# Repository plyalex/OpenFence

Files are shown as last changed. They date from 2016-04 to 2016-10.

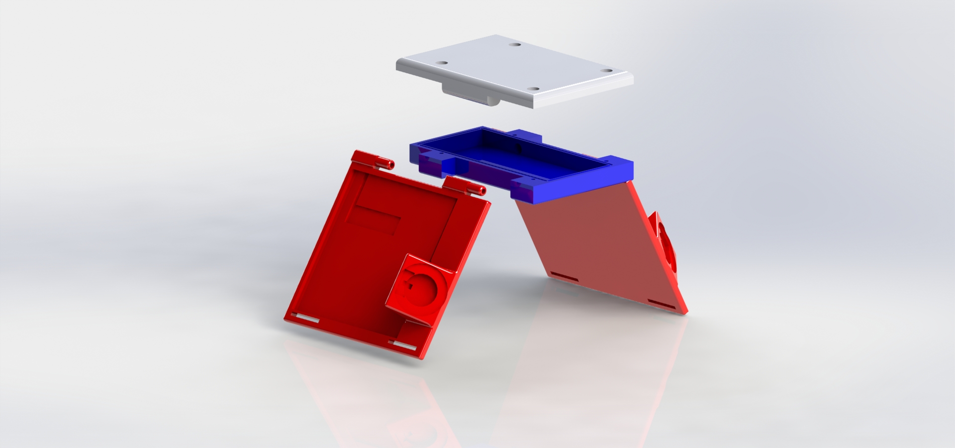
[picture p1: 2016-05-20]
hardware/solidworks/renders/Explodedv2.JPG

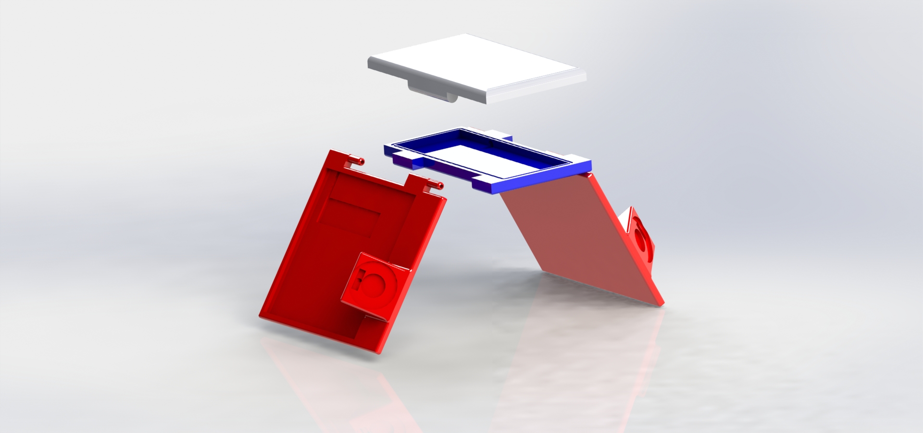
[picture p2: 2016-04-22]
hardware/solidworks/renders/Exploded.JPG

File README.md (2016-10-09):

#OpenFence
OpenFence is a digital livestock fencing system, which uses GPS and stereo audio alerts to contain animals within a specified boundary. 
The location of the fences can be updated using the web interface, and transferred to collar devices wirelessly using LoRa via the in field base station. 
The movements of the animals are logged and transferred to the web, to allow analysis of movements and land utilisation.
#The Purpose
OpenFence is designed to make it easier to implement productive and environmentally friendly grazing practises, such as cell grazing. 
This style of grazing has been shown to increase biodiversity, ground cover, soil carbon and water retention, however it is not commonly implemented due to the additional expenses of fencing and labour.
#Build Details
Go to the [HackaDay.io Page](https://hackaday.io/project/10725-openfence-digital-livestock-fencing)

#[Collar Code](https://github.com/plyalex/OpenFence/tree/master/software/collar/CollarSoftware)
Download and open with Arduino. Additional libraries required are: [TinyGPS++](https://github.com/mikalhart/TinyGPSPlus/releases) and RTCZero.

#Licence
All files: GNU GPL v3

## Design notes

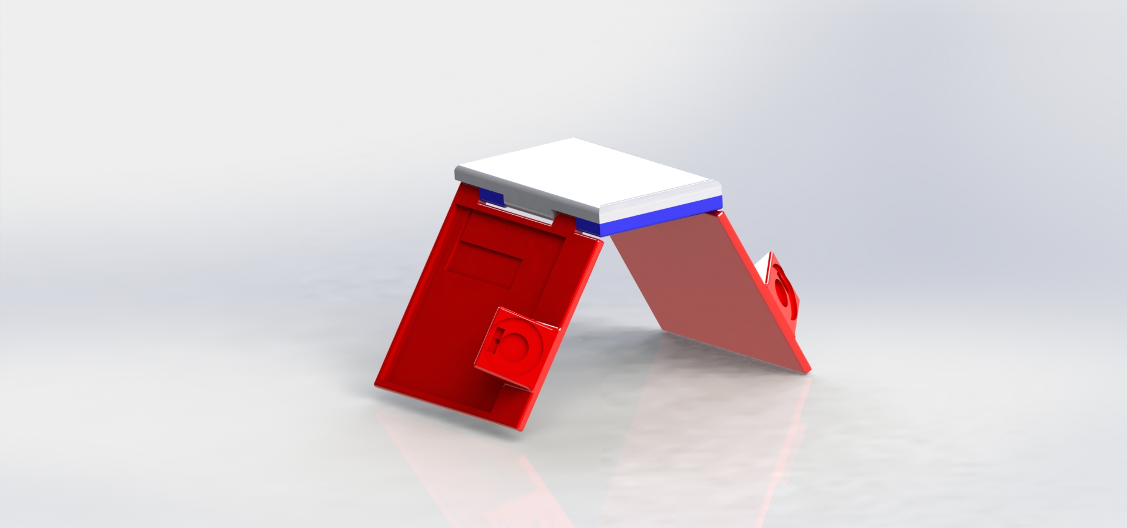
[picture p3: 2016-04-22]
hardware/solidworks/renders/Collar.JPG

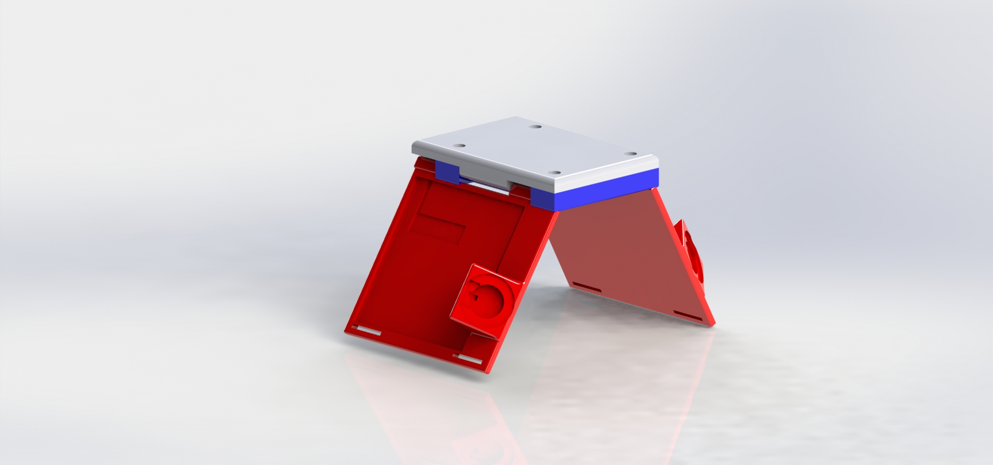
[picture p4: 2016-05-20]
hardware/solidworks/renders/Collarv2.JPG

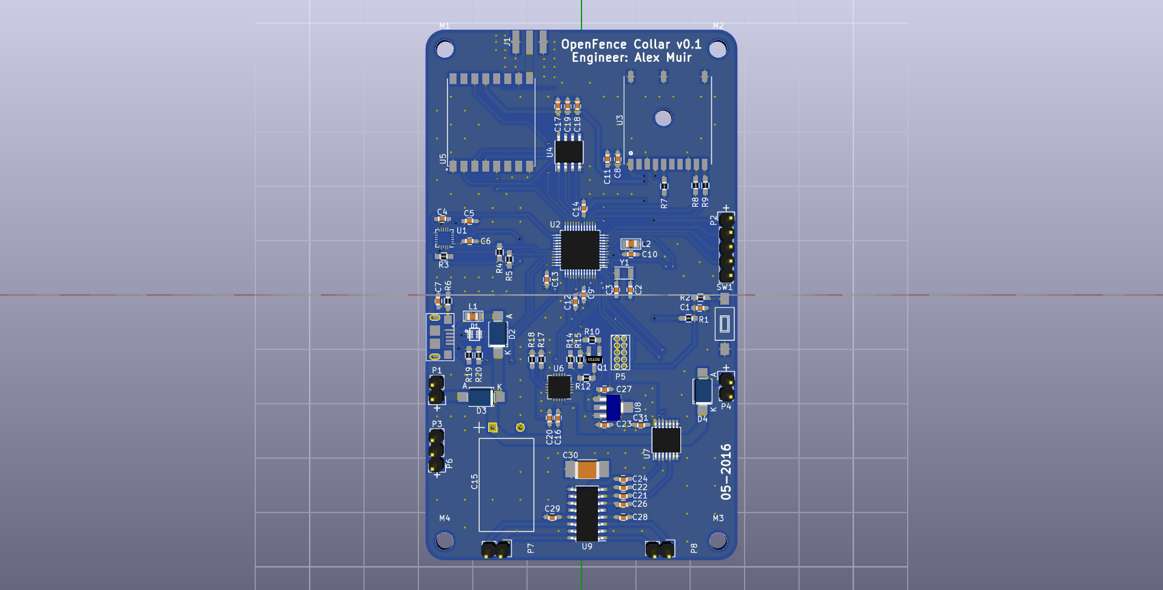
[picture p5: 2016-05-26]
hardware/pcbs/MainCollar/MainCollarRender2.png

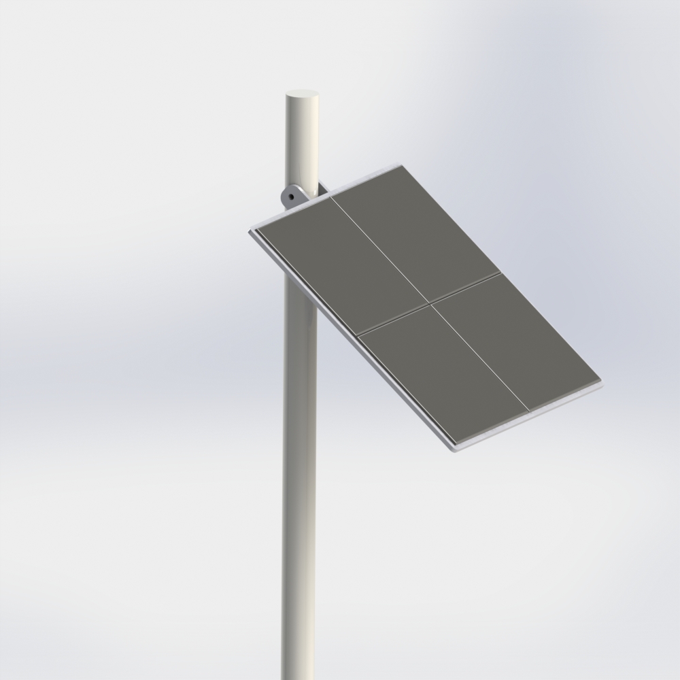
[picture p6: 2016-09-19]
hardware/solidworks/basestation/basestation.JPG

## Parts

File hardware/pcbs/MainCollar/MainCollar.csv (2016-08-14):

 | Reference | Value | Footprint | Datasheet
x | C1 | 0.1uF | Capacitors_SMD:C_0603_HandSoldering
x | C10 | 0.1uF | Capacitors_SMD:C_0603_HandSoldering
x | C11 | 0.01uF | Capacitors_SMD:C_0603_HandSoldering
x | C12 | 1uF | Capacitors_SMD:C_0603_HandSoldering
x | C13 | 0.1uF | Capacitors_SMD:C_0603_HandSoldering
x | C14 | 0.1uF | Capacitors_SMD:C_0603_HandSoldering
x | C15 | 2200uF | OpenFence:Cap1017
x | C16 | 4.7uF | Capacitors_SMD:C_0603_HandSoldering
x | C17 | 0.1uF | Capacitors_SMD:C_0603_HandSoldering
x | C18 | 0.1uF | Capacitors_SMD:C_0603_HandSoldering
x | C19 | 4.7uF | Capacitors_SMD:C_0603_HandSoldering
 | C2 | 18pF | Capacitors_SMD:C_0603_HandSoldering
x | C20 | 4.7uF | Capacitors_SMD:C_0603_HandSoldering
x | C21 | 0.47uF | Capacitors_SMD:C_0603_HandSoldering
x | C22 | 1uF | Capacitors_SMD:C_0603_HandSoldering
x | C23 | 4.7uF | Capacitors_SMD:C_0603_HandSoldering
x | C24 | 0.47uF | Capacitors_SMD:C_0603_HandSoldering
x | C26 | 1uF | Capacitors_SMD:C_0603_HandSoldering
x | C27 | 1uF | Capacitors_SMD:C_0603_HandSoldering
x | C28 | 1uF | Capacitors_SMD:C_0603_HandSoldering
x | C29 | 1uF | Capacitors_SMD:C_0603_HandSoldering
 | C3 | 18pF | Capacitors_SMD:C_0603_HandSoldering
x | C30 | 47uF | Capacitors_SMD:C_1812_HandSoldering
x | C31 | 0.1uF | Capacitors_SMD:C_0603_HandSoldering
x | C4 | 0.1uF | Capacitors_SMD:C_0603_HandSoldering
x | C5 | 0.01uF | Capacitors_SMD:C_0603_HandSoldering
x | C6 | 0.1uF | Capacitors_SMD:C_0603_HandSoldering
x | C7 | 4.7uF | Capacitors_SMD:C_0603_HandSoldering
x | C8 | 1uF | Capacitors_SMD:C_0603_HandSoldering
x | C9 | 0.1uF | Capacitors_SMD:C_0603_HandSoldering
 | D1 | USBLC6-2 | OpenFence:SOT666
x | D2 | SS24 | Diodes_SMD:SMA_Handsoldering
x | D3 | SS24 | Diodes_SMD:SMA_Handsoldering
x | D4 | SS24 | Diodes_SMD:SMA_Handsoldering
 | J1 | SMA-EDGE | RocketScreamKicadLibrary:RF-SMA-EDGE
x | L1 | 600R @ 100MHz | RocketScreamKicadLibrary:IND-0805
x | L2 | 600R @ 100MHz | RocketScreamKicadLibrary:IND-0805
 | P1 | USB_OTG | OpenFence:USB-10118193-0001LF
 | P6 | Battery | Pin_Headers:Pin_Header_Straight_1x03
x | Q1 | 2N7002 | TO_SOT_Packages_SMD:SOT-23_Handsoldering
 | R1 | 10K | Resistors_SMD:R_0603_HandSoldering
 | R10 | 100K | Resistors_SMD:R_0603_HandSoldering
 | R12 | 10K | Resistors_SMD:R_0603_HandSoldering
 | R14 | 270K | Resistors_SMD:R_0603_HandSoldering
 | R15 | 100K | Resistors_SMD:R_0603_HandSoldering
 | R17 | 1K | Resistors_SMD:R_0603_HandSoldering
 | R18 | 50K | Resistors_SMD:R_0603_HandSoldering
 | R19 | 100K | Resistors_SMD:R_0603_HandSoldering
 | R2 | 330 | Resistors_SMD:R_0603_HandSoldering
 | R20 | 330 | Resistors_SMD:R_0603_HandSoldering
 | R3 | 10K | Resistors_SMD:R_0603_HandSoldering
 | R4 | 10K | Resistors_SMD:R_0603_HandSoldering
 | R5 | 10K | Resistors_SMD:R_0603_HandSoldering
 | R6 | 1M | Resistors_SMD:R_0603_HandSoldering
 | R7 | 1K | Resistors_SMD:R_0603_HandSoldering
 | R8 | 1K | Resistors_SMD:R_0603_HandSoldering
 | R9 | 1K | Resistors_SMD:R_0603_HandSoldering
x | SW1 | SW_PUSH | Buttons_Switches_SMD:SW_SPST_FSMSM
 | U1 | MPU9250 | OpenFence:MPU9250
 | U2 | SAMD21G | Housings_QFP:TQFP-48_7x7mm_Pitch0.5mm
x | U3 | PA6C | OpenFence:PA6C
x | U4 | S25FL116K | Housings_SOIC:SOIC-8_3.9x4.9mm_Pitch1.27mm
 | U5 | RF95W | RocketScreamKicadLibrary:RFM9xW
 | U6 | MCP73871 | Housings_DFN_QFN:QFN-20-1EP_4x4mm_Pitch0.5mm
 | U7 | MAX5387 | Housings_SSOP:TSSOP-14_4.4x5mm_Pitch0.65mm
 | U8 | MCP1700T-3302E/MB | TO_SOT_Packages_SMD:SOT89-3_Housing_Handsoldering
 | U9 | PAM8403 | Housings_SOIC:SOIC-16_3.9x9.9mm_Pitch1.27mm
 | Y1 | 32.768kHz | OpenFence:FC-135

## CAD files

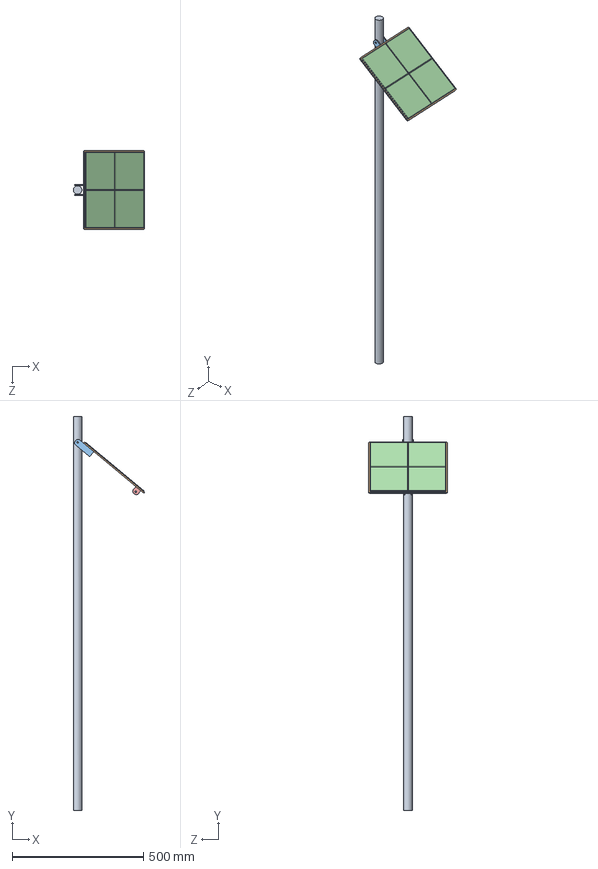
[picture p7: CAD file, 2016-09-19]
hardware/solidworks/basestation/Assem.SLDASM
271.6 x 1500.0 x 300.0 mm
pole
top
toplink x 2
solarpanel x 4
bottomlink x 2

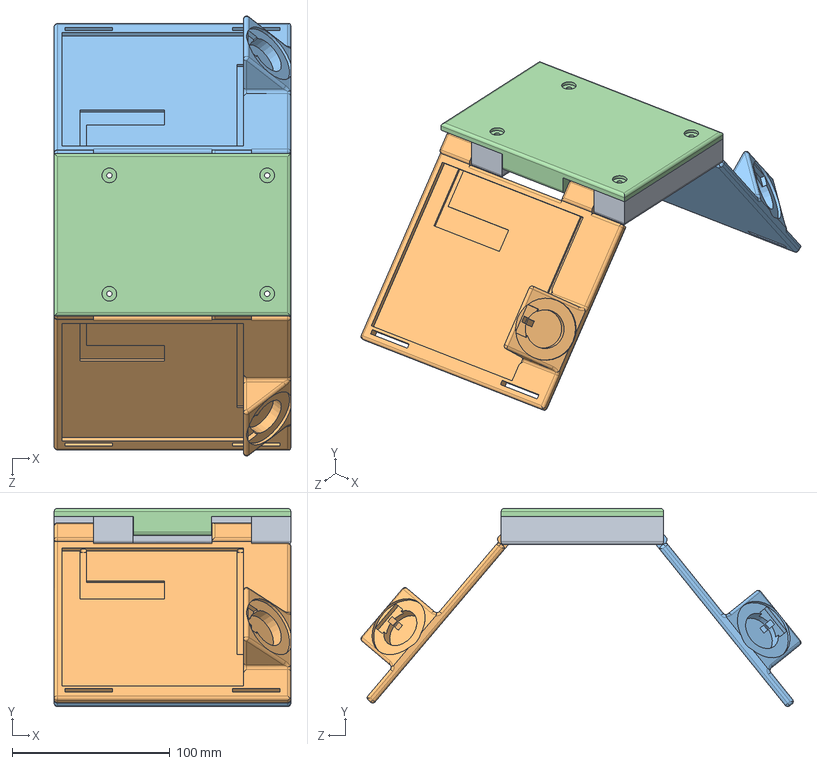
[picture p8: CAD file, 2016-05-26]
hardware/solidworks/Assembly.SLDASM
150.0 x 125.5 x 278.8 mm
BaseTop
RHS
LHS
LidTop
PCB

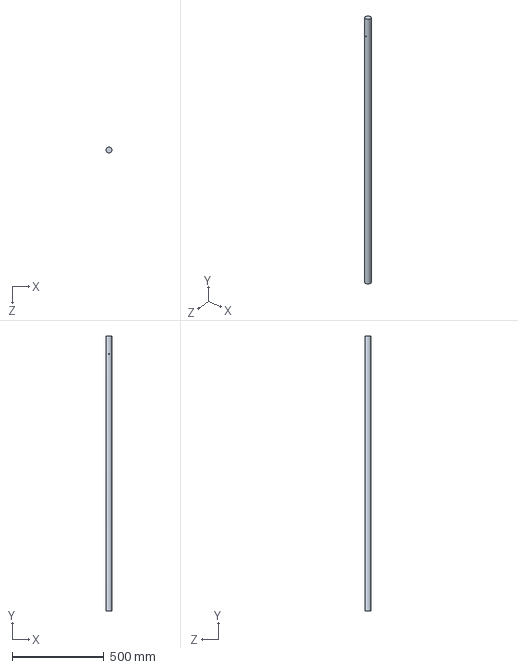
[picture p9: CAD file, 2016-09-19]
hardware/solidworks/basestation/pole.SLDPRT
32.5 x 1500.0 x 32.5 mm

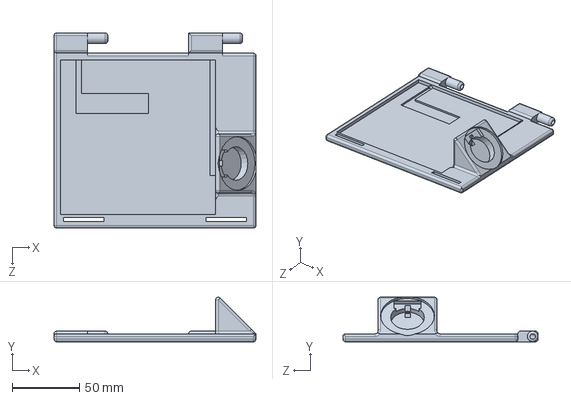
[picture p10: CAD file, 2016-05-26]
hardware/solidworks/RHS.SLDPRT
150.0 x 33.2 x 145.0 mm

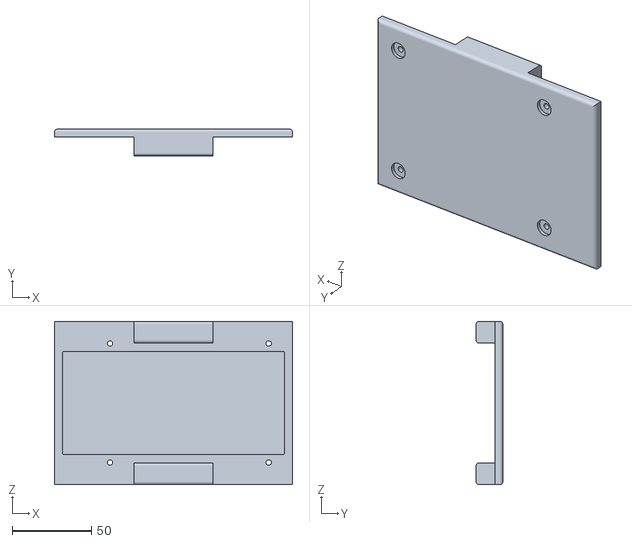
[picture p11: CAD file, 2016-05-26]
hardware/solidworks/stl/Rev2/EnclosureLidRev2.STL
150.0 x 17.0 x 103.0

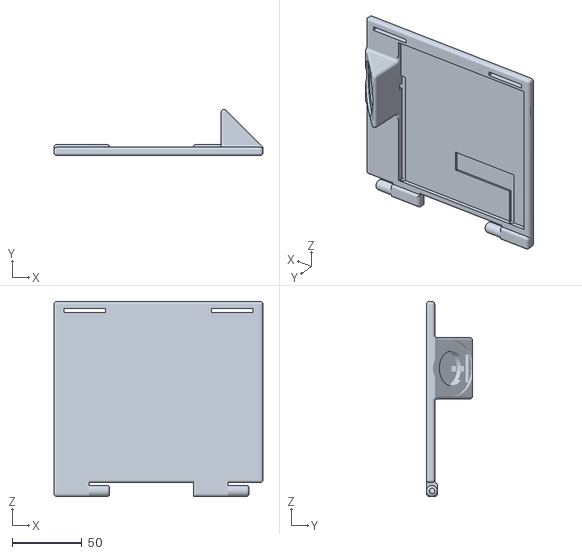
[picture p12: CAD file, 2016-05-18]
hardware/solidworks/stl/RHSRev1.STL
150.0 x 33.2 x 140.0

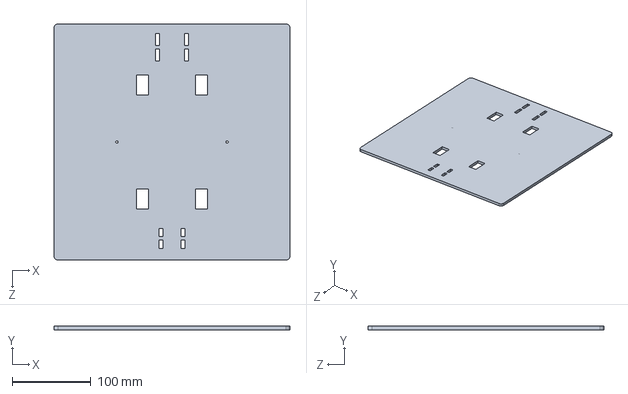
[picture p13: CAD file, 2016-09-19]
hardware/solidworks/basestation/top.SLDPRT
300.0 x 4.50 x 300.0 mm

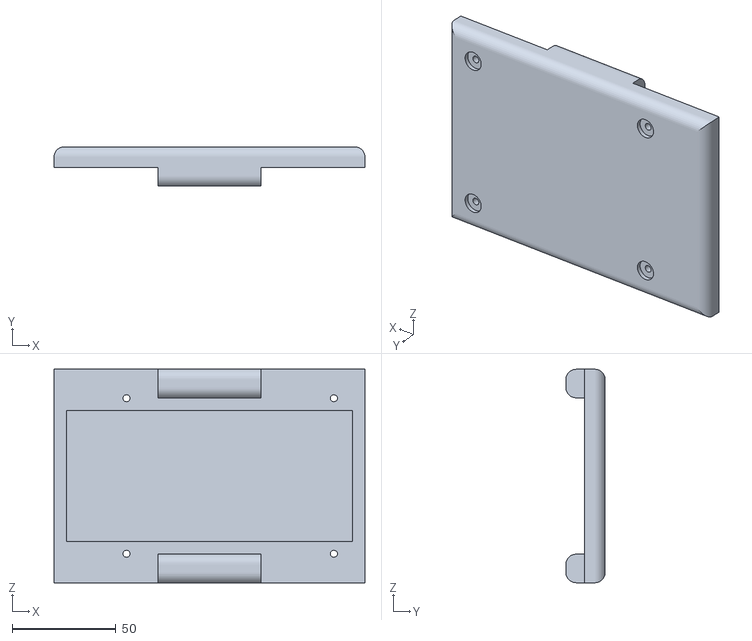
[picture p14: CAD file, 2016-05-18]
hardware/solidworks/stl/LidTopRev1.STL
150.0 x 19.0 x 103.0

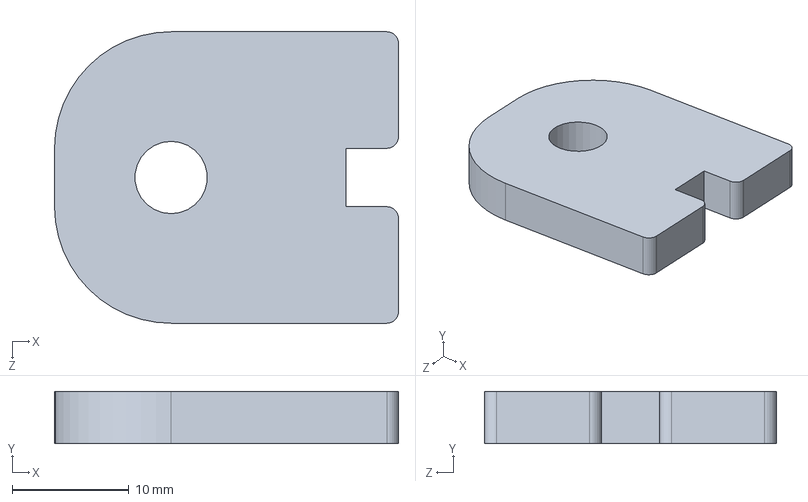
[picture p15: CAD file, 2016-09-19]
hardware/solidworks/basestation/bottomlink.SLDPRT
29.5 x 4.50 x 25.0 mm

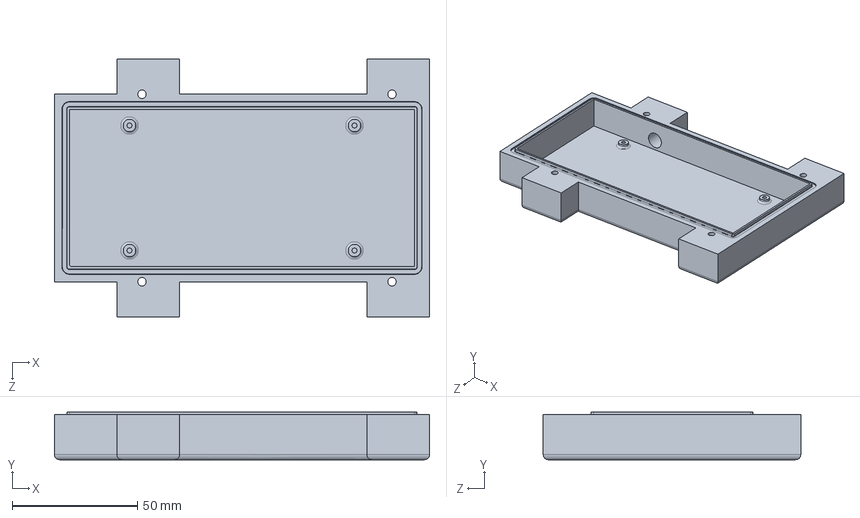
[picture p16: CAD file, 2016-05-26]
hardware/solidworks/BaseTop.SLDPRT
150.0 x 19.0 x 103.0 mm

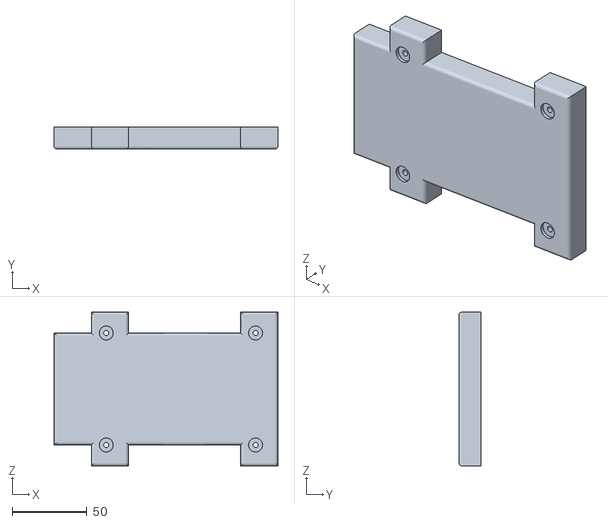
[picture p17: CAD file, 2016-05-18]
hardware/solidworks/stl/BaseTopRev1.STL
150.0 x 15.0 x 103.0

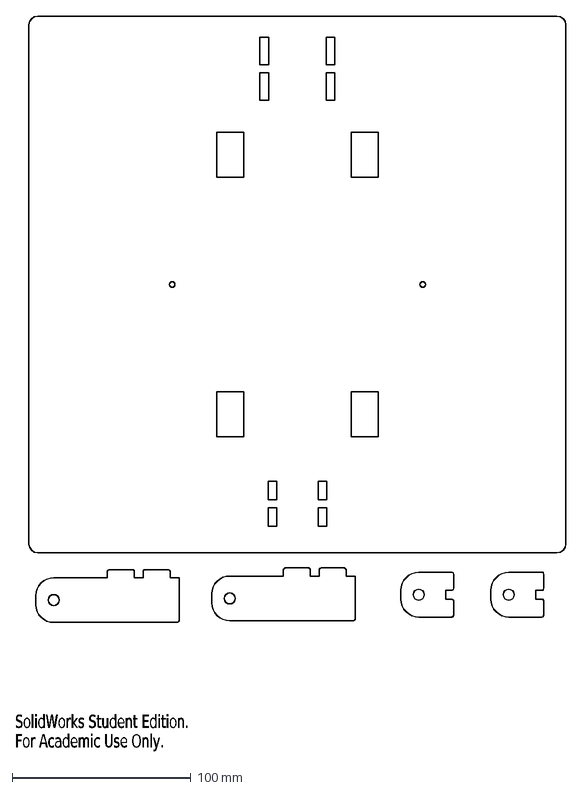
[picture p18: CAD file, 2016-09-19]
hardware/solidworks/basestation/AlexMuir-FYP.DXF
SolidWorks Student Edition.
For Academic Use Only.

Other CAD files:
hardware/solidworks/PCB.sldprt
hardware/solidworks/stl/Rev2/RightSideRev2.STL
hardware/solidworks/stl/LHSrev1.STL
hardware/solidworks/stl/Rev2/LeftSideRev2.STL
hardware/solidworks/LidTop.SLDPRT
hardware/solidworks/stl/Rev2/EnclosureBaseRev2.STL
hardware/solidworks/LHS.SLDPRT
hardware/solidworks/basestation/bottomlink.DXF
hardware/solidworks/basestation/sheet1.SLDDRW
hardware/solidworks/basestation/solarpanel.SLDPRT
hardware/solidworks/basestation/top.DXF
hardware/solidworks/basestation/toplink.DXF
hardware/solidworks/basestation/toplink.SLDPRT

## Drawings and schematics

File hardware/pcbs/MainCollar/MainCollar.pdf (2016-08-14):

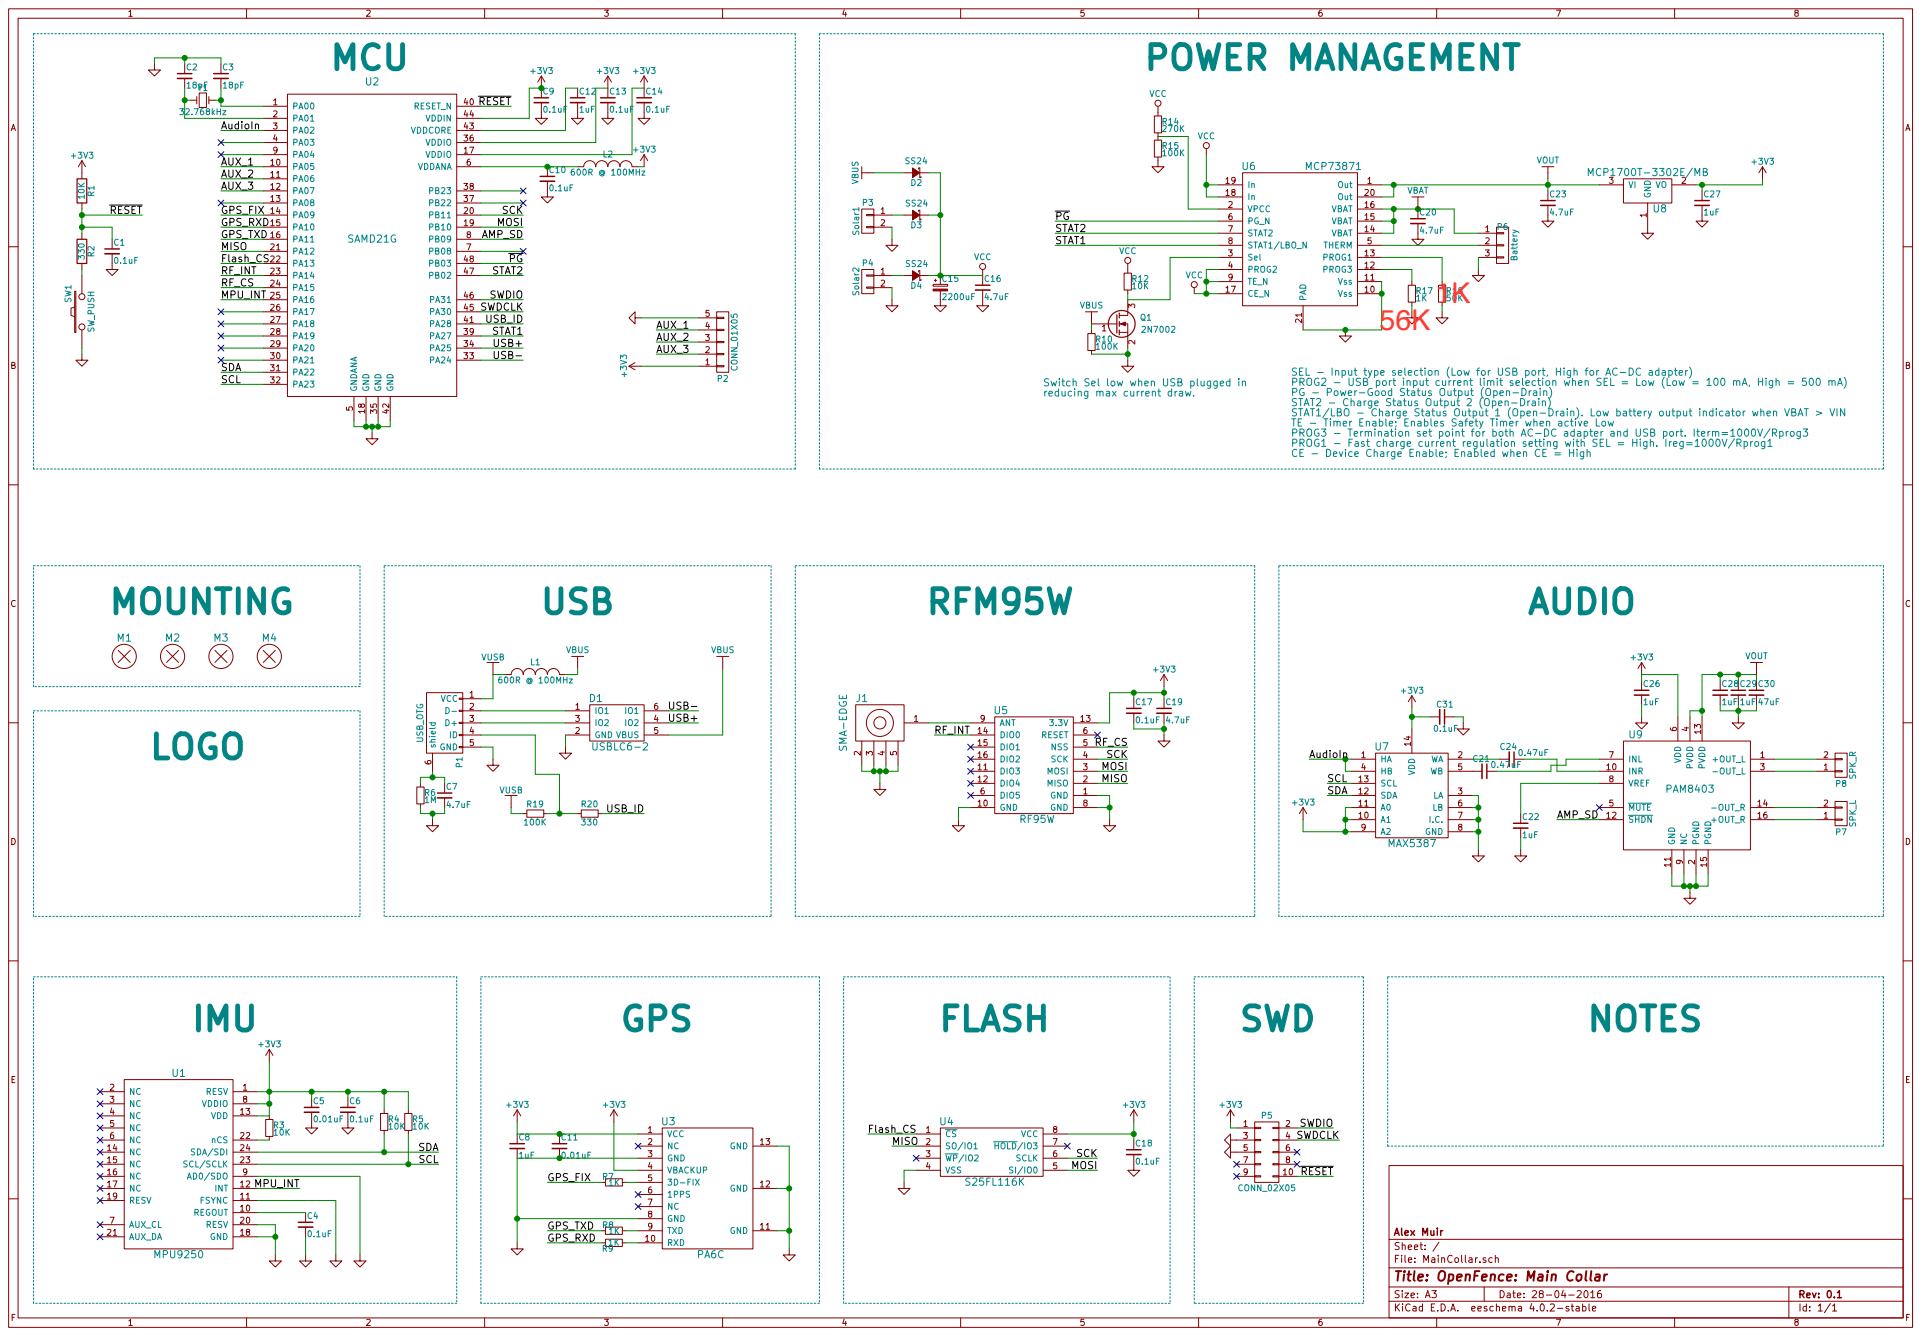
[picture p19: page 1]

PA17 26 | SWDCLK
PA18 27 | USB_ID
PA19 28 | STAT1

SEL - Input type selection (Low for USB port, High for AC-DC adapter)
PROG2 - USB port input current limit selection when SEL = Low (Low = 100 mA, High = 500 mA)
PG - Power-Good Status Output (Open-Drain)
STAT2 - Charge Status Output 2 (Open-Drain)
STAT1/LBO - Charge Status Output 1 (Open-Drain). Low battery output indicator when VBAT > VIN
TE - Timer Enable; Enables Safety Timer when active Low
PROG3 - Termination set point for both AC-DC adapter and USB port. Iterm=1000V/Rprog3
PROG1 - Fast charge current regulation setting with SEL = High. Ireg=1000V/Rprog1
CE - Device Charge Enable; Enabled when CE = High

Switch Sel low when USB plugged in
reducing max current draw.

DIO0 14 DIO1 15 | RF_CS

DIO2 16 | SCK

Alex Muir
Sheet: /
File: MainCollar.sch
Title: OpenFence: Main Collar

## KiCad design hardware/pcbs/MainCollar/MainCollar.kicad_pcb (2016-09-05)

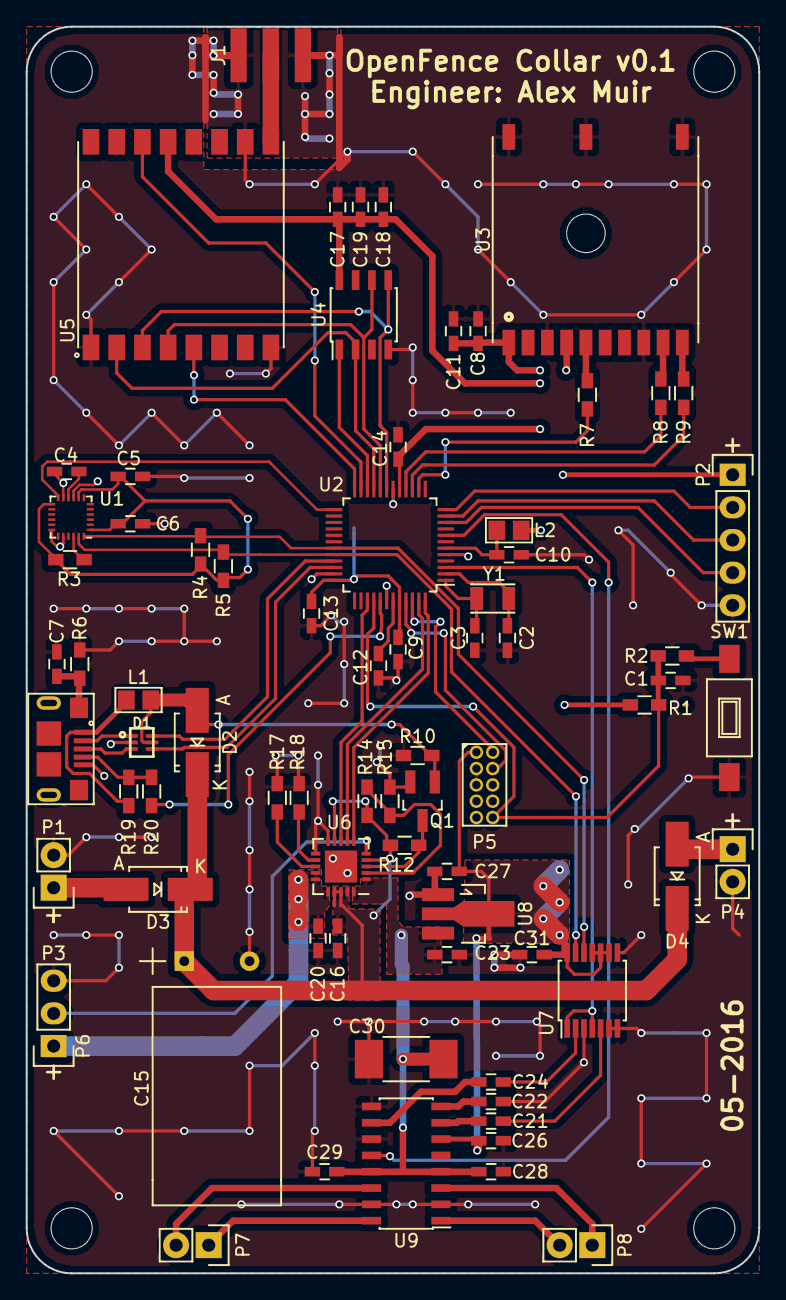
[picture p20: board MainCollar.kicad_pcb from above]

Board: 2 copper layers, 57.0 x 97.0 mm, 78 parts (0 on the bottom side), 64 nets.

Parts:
C1, C4, C6, C9, C10, C13, C14, C17, C18, C31: 0.1uF; C_0603_HandSoldering
C2, C3: 18pF; C_0603_HandSoldering
C5, C11: 0.01uF; C_0603_HandSoldering
C7, C16, C19, C20, C23: 4.7uF; C_0603_HandSoldering
C8, C12, C22, C26, C27, C28, C29: 1uF; C_0603_HandSoldering
C15: 2200uF; Cap1017
C21, C24: 0.47uF; C_0603_HandSoldering
C30: 47uF; C_1812_HandSoldering
D1: USBLC6-2; SOT666
D2, D3, D4: SS24; SMA_Handsoldering
J1: SMA-EDGE; RF-SMA-EDGE
L1, L2: 600R @ 100MHz; IND-0805
M1, M2, M3, M4: Mounting_Hole; MountingHole_3.2mm_M3
P1: USB_OTG; USB-10118193-0001LF
P2: CONN_01X05; Pin_Header_Straight_1x05
P3: Solar1; Pin_Header_Straight_1x02
P4: Solar2; Pin_Header_Straight_1x02
P5: CONN_02X05; HDR_2x5_Pitch1.27mm
P6: Battery; Pin_Header_Straight_1x03
P7: SPK_L; Pin_Header_Straight_1x02
P8: SPK_R; Pin_Header_Straight_1x02
Q1: 2N7002; SOT-23_Handsoldering
R1, R3, R4, R5, R12: 10K; R_0603_HandSoldering
R2, R20: 330; R_0603_HandSoldering
R6: 1M; R_0603_HandSoldering
R7, R8, R9, R17: 1K; R_0603_HandSoldering
R10, R15, R19: 100K; R_0603_HandSoldering
R14: 270K; R_0603_HandSoldering
R18: 50K; R_0603_HandSoldering
SW1: SW_PUSH; SW_SPST_FSMSM
U1: MPU9250
U2: SAMD21G; TQFP-48_7x7mm_Pitch0.5mm
U3: PA6C
U4: S25FL116K; SOIC-8_3.9x4.9mm_Pitch1.27mm
U5: RF95W; RFM9xW
U6: MCP73871; QFN-20-1EP_4x4mm_Pitch0.5mm
U7: MAX5387; TSSOP-14_4.4x5mm_Pitch0.65mm
U8: MCP1700T-3302E/MB; SOT89-3_Housing_Handsoldering
U9: PAM8403; SOIC-16_3.9x9.9mm_Pitch1.27mm
Y1: 32.768kHz; FC-135

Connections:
+3V3: C5.1, C6.1, C8.1, C9.1, C11.1, C13.1, C14.1, C17.1, C18.1, C19.1, C26.1, C27.1, C31.2, L2.2, P2.1, P5.1, R1.1, R3.1, R4.1, R5.1, U1.1, U1.8, U1.13, U2.17, U2.36, U2.44, U3.1, U3.4, U4.8, U5.13, U7.9, U7.10, U7.11, U7.14, U8.2, U9.6
/AMP_SD: U2.8, U9.12
/AUX_1: P2.4, U2.10
/AUX_2: P2.3, U2.11
/AUX_3: P2.2, U2.12
/AudioIn: U2.3, U7.1, U7.4
/Flash_CS: U2.22, U4.1
/GPS_FIX: R7.1, U2.14
/GPS_RXD: R9.2, U2.15
/GPS_TXD: R8.1, U2.16
/MISO: U2.21, U4.2, U5.2
/MOSI: U2.19, U4.5, U5.3
/MPU_INT: U1.12, U2.25
/RF_CS: U2.24, U5.5
/RF_INT: U2.23, U5.14
/SCK: U2.20, U4.6, U5.4
/SCL: R5.2, U1.23, U2.32, U7.13
/SDA: R4.2, U1.24, U2.31, U7.12
/STAT1: U2.39, U6.8
/STAT2: U2.47, U6.7
/SWDCLK: P5.4, U2.45
/SWDIO: P5.2, U2.46
/USB+: D1.4, U2.34
/USB-: D1.6, U2.33
/USB_ID: R20.1, U2.41
/~PG: U2.48, U6.6
/~RESET~: C1.1, P5.10, R1.2, R2.1, U2.40
GND: C1.2, C2.1, C3.1, C4.2, C5.2, C6.2, C7.2, C8.2, C9.2, C10.2, C11.2, C12.2, C13.2, C14.2, C15.2, C16.2, C17.2, C18.2, C19.2, C20.2, C22.2, C23.2, C26.2, C27.2, C28.2, C29.2, C30.2, C31.1, D1.2, J1.2, J1.3, J1.4, J1.5, P1.5, P2.5, P3.2, P4.2, P5.3, P5.5, P6.3, Q1.2, R6.2, R10.2, R15.2, R17.2, R18.2, SW1.1, U1.9, U1.11, U1.18, U1.20, U2.5, U2.18, U2.35, U2.42, U3.3, U3.8, U3.11, U3.12, U3.13, U4.4, U5.1, U5.8, U5.10, U6.10, U6.11, U6.21, U7.3, U7.6, U7.7, U7.8, U8.1, U9.2, U9.9, U9.11, U9.15
unnamed: C2.2, U2.2, Y1.1
unnamed: C3.2, U2.1, Y1.2
unnamed: C4.1, U1.10
unnamed: C7.1, P1.6, R6.1
unnamed: C10.1, L2.1, U2.6
unnamed: C12.1, U2.43
unnamed: C21.1, U9.7
unnamed: C21.2, U7.5
unnamed: C22.1, U9.8
unnamed: C24.1, U9.10
unnamed: C24.2, U7.2
unnamed: D1.1, P1.2
unnamed: D1.3, P1.3
unnamed: D3.2, P3.1
unnamed: D4.2, P4.1
unnamed: J1.1, U5.9
unnamed: P1.4, R19.1, R20.2
unnamed: P6.2, U6.5
unnamed: P7.1, U9.16
unnamed: P7.2, U9.14
unnamed: P8.1, U9.3
unnamed: P8.2, U9.1
unnamed: Q1.3, R12.2, U6.3
unnamed: R2.2, SW1.2
unnamed: R3.2, U1.22
unnamed: R7.2, U3.5
unnamed: R8.2, U3.9
unnamed: R9.1, U3.10
unnamed: R14.2, R15.1, U6.2
unnamed: R17.1, U6.13
unnamed: R18.1, U6.12
VBAT: C20.1, P6.1, U6.14, U6.15, U6.16
VBUS: D1.5, D2.2, L1.2, Q1.1, R10.1
VCC: C15.1, C16.1, D2.1, D3.1, D4.1, R12.1, R14.1, U6.4, U6.9, U6.17, U6.18, U6.19
VOUT: C23.1, C28.1, C29.1, C30.1, U6.1, U6.20, U8.3, U9.4, U9.13
VUSB: L1.1, P1.1, R19.2

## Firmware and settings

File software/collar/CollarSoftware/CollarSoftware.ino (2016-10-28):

#include "PinDefines.h"
#include "MCP73871.h"
#include "MPU9250.h"
#include "Audio_OF.h"
#include "LoRa_OF.h"
#include "Geofence.h"
#include <Wire.h>
#include <SPI.h>
#include <RTCZero.h>
#include <TinyGPS++.h>
#include "Flash_OF.h"


#define GPSTestPoints
uint8_t NODE_ADDRESS = 103;
uint8_t distThresh = 2;
uint8_t motionThresh = 3;
bool testing = true;
int16_t magbias0 = -270;
int16_t magbias1 = 168;
int16_t magbias2 = -70;

uint8_t polyCorners = 0;
struct position fencePoints[256];
uint8_t fenceversion = 0;

MCP73871 battery;
RTCZero rtc;
TinyGPSPlus gps;
MPU9250 mpu9250;
Audio_OF audio;
LoRa_OF lora;
Flash_OF flash;
Geofence fence;


// magbias[]={-90,400,0}; //Float in MPU9250.h library


position me, metransmitted;
datetime nowdt;
int alerts = 0;
int shocks = 0;
int sleepCounter = 0;




void setup() {
  init_pins();
  init_comms();
  delay(3000);
  init_gps();
  audio.initAudio();
  rtc.begin(); // initialize RTC

  fencePoints[0].lon=145.138458;  
  fencePoints[0].lat=-37.911625; 
  fencePoints[1].lon=145.138707;
  fencePoints[1].lat=-37.911662;
  fencePoints[2].lon=145.138653;
  fencePoints[2].lat=-37.911887;
  fencePoints[3].lon=145.138399; 
  fencePoints[3].lat=-37.911850;
  polyCorners=4;

  delay(1000);
  lora.initLoRa();
  flash.init();  
  lora.setAddress();

  SerialUSB.print(magbias0); SerialUSB.print("\t");
  SerialUSB.print(magbias1); SerialUSB.print("\t");
  SerialUSB.print(magbias2); SerialUSB.println("\t");

  init_mpu();


// Re enable me for sleep mode??
 // mpu9250.wakeOnmotion(motionThresh);
 // mpu9250.readStatus();


  // while(1){
  //   float compass = mpu9250.getHeading();
  //   compass = compass + 11.716667;
  //   SerialUSB.println(compass);
  //   // while (GPSSerial.available())
  //   //   SerialUSB.write(GPSSerial.read());
  //   delay(200);
  // }

  // int vol = 50;
  // while(1){
  //   SerialUSB.print("Volume: "); SerialUSB.println(vol);
  //   audio.enableAmp(); 
  //   audio.setvolumeBoth(vol); 
  //   delay(1500);
  //   vol=vol+2; 
  //   audio.disableAmp(); 
  //   delay(1000);
  // }

  testing = 1;
  // motionThresh = 3;

  

  SerialUSB.print(NODE_ADDRESS); SerialUSB.print("\t");
  SerialUSB.print(polyCorners); SerialUSB.print("\t");
  SerialUSB.print(fenceversion); SerialUSB.print("\t");
  SerialUSB.print(fencePoints[0].lat,7); SerialUSB.print("\t");
  SerialUSB.print(fencePoints[1].lat,7); SerialUSB.print("\t");
  SerialUSB.print(fencePoints[2].lat,7); SerialUSB.print("\t");
  SerialUSB.println(fencePoints[3].lat,7);
  SerialUSB.print(magbias0); SerialUSB.print("\t");
  SerialUSB.print(magbias1); SerialUSB.print("\t");
  SerialUSB.print(magbias2); SerialUSB.println("\t");

  SerialUSB.println("Setup Complete");
  audio.enableAmp(); audio.setvolumeBoth(20); delay(500); audio.disableAmp(); // Short Beep

  if(testing){
    audio.enableAmp(); audio.setvolumeBoth(20); delay(500); audio.disableAmp(); //Beep Beep
    delay(500); audio.enableAmp(); delay(500); audio.disableAmp();
    me.lat=-37.909507; 
    me.lon=145.135128;
    nowdt.time=60005;
    nowdt.date=191016;
    metransmitted=me;
  }

  if(!testing){
    SerialUSB.print("Getting GPS Fix");
    while(!gps.location.isValid())
      smartDelay(500);
    SerialUSB.println("Fix Obtained");
    updateMeNowDT();
    metransmitted=me;

    audio.enableAmp(); audio.setvolumeBoth(20); delay(500); audio.disableAmp(); //Beep Beep
    delay(500); audio.enableAmp(); delay(500); audio.disableAmp();
  }
}

void loop() {
  

  //battery.printStatus();
  //SerialUSB.println(battery.getStatus(),BIN);
  //SerialUSB.println(fencePoints[0].lat);

  if(!testing){
    updateMeNowDT();
  // } else {
  //   byte seconds=rtc.getSeconds();
  //   if(seconds < 10){     //Inside
  //     me.lat=-37.911765; 
  //     me.lon=145.138300;
  //     nowdt.time=51810;
  //     nowdt.date=240516;
  //   }else if(seconds <20){
  //     me.lat=-37.911643; 
  //     me.lon= 145.137766;
  //     nowdt.time=51820;
  //     nowdt.date=240516;
  //   }else if(seconds <30){
  //     me.lat=-37.911623;
  //     me.lon=145.137901;
  //     nowdt.time=51830;
  //     nowdt.date=240516;
  //   }else if(seconds <40){
  //     me.lat=-37.911520;
  //     me.lon=145.138454;
  //     nowdt.time=51840;
  //     nowdt.date=240516;
  //   }else if(seconds <50){
  //     me.lat=-37.911997;
  //     me.lon=145.138565;
  //     nowdt.time=51850;
  //     nowdt.date=240516;
  //   }else if(seconds <60){
  //     me.lat=-37.912090;
  //     me.lon=145.138230;
  //     nowdt.time=51900;
  //     nowdt.date=240516;
  //   }
  // }
  } else {
    byte seconds=rtc.getSeconds();
    if(seconds < 5){     //Inside
      me.lat=-37.909507; 
      me.lon=145.135128;
      nowdt.time=60005;
      nowdt.date=191016;
    }else if(seconds <10){ //inside
      me.lat=-37.909630; 
      me.lon= 145.135133;
      nowdt.time=60010;
      nowdt.date=191016;
    }else if(seconds <15){ //outside
      me.lat=-37.909624; 
      me.lon=145.135013;
      nowdt.time=60015;
      nowdt.date=191016;
    }else if(seconds <20){ //outside
      me.lat=-37.909623; 
      me.lon=145.134983;
      nowdt.time=60020;
      nowdt.date=191016;
    }else if(seconds <25){ //outside
      me.lat=-37.909623; 
      me.lon=145.134972;
      nowdt.time=60025;
      nowdt.date=191016;
    }else if(seconds <30){ //outside
      me.lat=-37.909673; 
      me.lon=145.134976;
      nowdt.time=60030;
      nowdt.date=191016;
    }else if(seconds <35){ //outside
      me.lat=-37.909704; 
      me.lon=145.135008;
      nowdt.time=60035;
      nowdt.date=191016;
    }else if(seconds <40){ //inside
      me.lat=-37.909729; 
      me.lon= 145.135105;
      nowdt.time=60040;
      nowdt.date=191016;
    }else if(seconds <45){ //inside
      me.lat=-37.909750;
      me.lon=145.135287;
      nowdt.time=60005;
      nowdt.date=191016;
    }else if(seconds <50){ //inside
      me.lat=-37.909647; 
      me.lon=145.135288;
      nowdt.time=60050;
      nowdt.date=191016;
    }else if(seconds <55){ //inside
      me.lat=-37.909506; 
      me.lon=145.135305;
      nowdt.time=60055;
      nowdt.date=191016;
    }
  }

  if(fence.distance(me, metransmitted) > distThresh){
    sleepCounter = 0; //Recent Movement
    //SerialUSB.println("Sending Packet");
    if(lora.sendPosition(me, nowdt, alerts, shocks, fenceversion)){
      // audio.enableAmp(); audio.setvolumeBoth(20); delay(500); audio.disableAmp(); //Beep Beep Failed to Send
      // delay(500); audio.enableAmp(); delay(500); audio.disableAmp();
    } else {
      metransmitted=me;
    }
  }



  fenceProperty result=fence.geofence(me, fencePoints, polyCorners);

  float compass = mpu9250.getHeading();

  
  SerialUSB.println(compass);


  static bool outside;

  if(result.distance > 0){
    SerialUSB.print("Side: \t");
    SerialUSB.print(result.sideOutside);
    SerialUSB.print("\t Distance: \t");
    SerialUSB.print(result.distance);
    SerialUSB.print("\t Azimuth: \t");
    SerialUSB.print(result.bearing);
    SerialUSB.print("\t Compass: \t");
    SerialUSB.print(compass);
    SerialUSB.println("\t C+var-A: \t");


    if(!outside){
      alerts++;
      outside=1;
    } 
    
    int volume = result.distance * 10; //10;
    //if(volume>10) volume=10;
    if(volume>50) volume=50;
    audio.enableAmp();
    audio.setvolumeBoth(volume);
    // delay(1000);
    // audio.disableAmp();

    int val = compass + 11.716667 + result.bearing;
    while(abs(val)>180){
      if(val > 180) val=val-360;
      else if(val < -180) val=val+360;
    }
    SerialUSB.println(val);

    if(val>0){
      if(val>90){
        audio.setvolumeBoth(0);
        audio.disableAmp();
      }
      else{
        //Sound RHS
        audio.enableAmp();
        audio.setvolumeLeft(0);
        audio.setvolumeRight(volume);
      } 
    }
    else{
      if(val < -90){
        audio.setvolumeBoth(0);
        audio.disableAmp();
      }
      else{
        //Sound LHS
        audio.enableAmp();
        audio.setvolumeRight(0);
        audio.setvolumeLeft(volume);
      } 
    }
  }else{
    outside=0;
    audio.setvolumeBoth(0);
    audio.disableAmp();
  }

  smartDelay(500);
  
  sleepCounter++;
  if(sleepCounter > 15 & !outside & !testing){
    sleepCounter=0;
    //audio.enableAmp(); audio.setvolumeBoth(20); delay(1000); audio.disableAmp(); // Long Beep    
    standby();
    //audio.enableAmp(); audio.setvolumeBoth(20); delay(500); audio.disableAmp(); // Short Beep
  }

}


static void smartDelay(unsigned long ms)
{
  unsigned long start = millis();
  do 
  {
    while (GPSSerial.available())
      gps.encode(GPSSerial.read());
  } while (millis() - start < ms);
}

void updateMeNowDT(){
  if (gps.location.isValid())
  {
    me.lat=gps.location.lat();
    me.lon=gps.location.lng();
  }
  if (gps.date.isValid())
  {
    nowdt.date=gps.date.value();
  }      
  if (gps.time.isValid())
  {
    nowdt.time=gps.time.value()/100; //Divide by 100 to remove fractions of a second
  } 
}

void standbyGPS(){
  GPSSerial.println("$PMTK161,0*28"); //Send GPS to Standby (wake with any char)
  delay(100);  //Ensure the GPS Serial Message has time to complete before sleeping
}

void standbyMode()
{
  SCB->SCR |= SCB_SCR_SLEEPDEEP_Msk;
  __DSB();
  __WFI();
  return;
}

void wake(){
  mpu9250.readStatus();
  return;
}

void standby(){
  standbyGPS();
  lora.sleep();
  audio.disableAmp();
  mpu9250.wakeOnmotion(motionThresh);
  mpu9250.readStatus();
  attachInterrupt(11, wake, HIGH);
  USBDevice.detach();
  delay(100);
  //USBDevice.detach();
  
  standbyMode();

  detachInterrupt(11);
  USBDevice.attach();
  standbyGPS();  //wakes GPS back up

  return;
}

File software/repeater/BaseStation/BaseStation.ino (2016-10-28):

// ***** INCLUDES *****
#include <RHReliableDatagram.h>
#include <RH_RF95.h>
#include <SPI.h>

// ***** CONSTANTS *****
#define BASE_STATION_ADDRESS 1
#define SerialMethod SerialUSB
//#define SerialMethod Serial1


// ***** PIN DEFINITION *****
// ***** MINI ULTRA PRO CONFIGURATIONS *****
const int radioInterruptPin = 2;  // D2 is used as radio interrupt pin
const int flashChipSelectPin = 4; // D4 is used as serial flash chip select pin
const int radioChipSelectPin = 5; // D5 is used as radio chip select pin
const int ledPin = 13;            // D13 has an LED 

// Singleton instance of the radio driver
RH_RF95 radio(radioChipSelectPin, radioInterruptPin);

// Class to manage message delivery and receipt, using the driver declared above
RHReliableDatagram manager(radio, BASE_STATION_ADDRESS);


uint8_t buf[RH_RF95_MAX_MESSAGE_LEN];
uint8_t buffer[20];

struct datapacket0{ //Animal Locations
  float lat;
  float lon;
  uint32_t gpstime;
  uint32_t date;
  uint16_t alerts; 
  uint8_t shocks;
  uint8_t ver;
};

struct datapacket1{ //Fence Locations
  uint8_t ver;
  uint8_t last;
  uint8_t numPts;
  uint8_t X;
  float lat0;
  float lon0;
  float lat1;
  float lon1;
};

struct datapacket2{ //Settings
  bool updated;
  uint8_t New_RF_ID;
  uint8_t distThresh;
  uint8_t motionThresh;
  bool testing;
  //uint8_t Padding will be added
  int16_t magbias0;
  int16_t magbias1;
  int16_t magbias2;
};

struct position{
  float lat; //x
  float lon; //y
};

int polyCorners = 0;
uint8_t fenceversion;


struct datapacket0 d0; //Received Location 
struct datapacket1 d1[128]; //Fence Locations
struct datapacket2 d2[256]; //Collar Settings


void setup() 
{
  // Ensure serial flash is not interfering with radio communication on SPI bus
  pinMode(flashChipSelectPin, OUTPUT);
  digitalWrite(flashChipSelectPin, HIGH);
  
  pinMode(ledPin, OUTPUT);
  digitalWrite(ledPin, LOW);
    
  SerialMethod.begin(57600);
  digitalWrite(ledPin, HIGH);
  // If radio initialization fail
  if (!manager.init())
  {
    SerialMethod.println("Init failed");
  }
  else SerialMethod.println("Init Success");

  digitalWrite(ledPin, LOW);


  // FSK, Rb = 2.4 kbps, Fd = 4.8 kHz 915 MHz, 20 dBm on RFM69HCW
  radio.setModemConfig(RH_RF95::Bw500Cr45Sf128 );
  radio.setFrequency(915.0);
  radio.setTxPower(5);


  d1[0].ver=1;
  d1[0].last=0;
  d1[0].numPts=3;
  d1[0].X=0;
  d1[0].lon0=101.101101;  
  d1[0].lat0=-37.911625; 
  d1[0].lon1=145.138707;
  d1[0].lat1=-37.911662;
  d1[1].ver=1;
  d1[1].last=1;
  d1[1].numPts=3;
  d1[1].X=2;
  d1[1].lon0=145.138653;
  d1[1].lat0=-37.911887;
  d1[1].lon1=0;
  d1[1].lat1=0;
}



void loop()
{


  uint8_t flag=0;
  uint8_t index=0;
  uint8_t length=0;

  if(SerialMethod.available()){

    flag = SerialMethod.read();
    length = SerialMethod.read();
    if(length > 20) length = 20;

    for(int j=0; j<length; j++){
      buffer[j]=SerialMethod.read();
    }

    switch(flag){
      case 1: //New Fence locations
              memcpy(&index,          &buffer[3],  1);
              index=index>>1; //Divide by two

              if(index==0) memset(&d1[0], 0, sizeof(d1));  //If new set of fence points, remove the old ones.

              memcpy(&d1[index].ver,       &buffer[0],  1);   //Dest, Orig, Bytes
              memcpy(&d1[index].last,      &buffer[1],  1);
              memcpy(&d1[index].numPts,    &buffer[2],  1);
              memcpy(&d1[index].X,         &buffer[3],  1);
              memcpy(&d1[index].lat0,      &buffer[4],  4);
              memcpy(&d1[index].lon0,      &buffer[8],  4);
              memcpy(&d1[index].lat1,      &buffer[12], 4);
              memcpy(&d1[index].lon1,      &buffer[16], 4);
              break;

      case 2: //Setting Update
              memcpy(&index,          &buffer[0],  1); //RF_ID
              d2[index].updated = 1;

              memcpy(&d2[index].New_RF_ID,      &buffer[1],  1);   //Dest, Orig, Bytes
              memcpy(&d2[index].distThresh,     &buffer[2],  1);
              memcpy(&d2[index].motionThresh,   &buffer[3],  1);
              memcpy(&d2[index].testing,        &buffer[4],  1);
              memcpy(&d2[index].magbias0,       &buffer[5],  2);
              memcpy(&d2[index].magbias1,       &buffer[7],  2);
              memcpy(&d2[index].magbias2,       &buffer[9],  2);
              break;

    }
    
}

  // Message available from mobile node?
  if (manager.available())
  {
    uint8_t len = sizeof(buf);
    uint8_t from;
    uint8_t* bufPtr;
    digitalWrite(ledPin, HIGH);  
    // Now wait for a reply from the mobile node
    if (manager.recvfromAck(buf, &len, &from))
    {
      uint8_t flagfromNode = radio.headerFlags();
      switch(flagfromNode){
        case 0: //Location packet
                memcpy(&d0.lat,      &buf[0],  4);   //Dest, Orig, Bytes
                memcpy(&d0.lon,      &buf[4],  4);
                memcpy(&d0.gpstime,  &buf[8],  4);
                memcpy(&d0.date,     &buf[12], 4);
                memcpy(&d0.alerts,   &buf[16], 2);
                memcpy(&d0.shocks,   &buf[18], 1);
                memcpy(&d0.ver,      &buf[19], 1);


                SerialMethod.write((uint8_t *)&flagfromNode,1);
                SerialMethod.write((uint8_t *)&from,1);
                SerialMethod.write((uint8_t *)&d0,20);
                SerialMethod.println();

          //Human Readable
                // SerialMethod.print(from); SerialMethod.print(","); SerialMethod.print(radio.headerFlags());SerialMethod.print(",");
                // SerialMethod.print(d0.lat,6); SerialMethod.print(d0.lon,6); SerialMethod.print(","); SerialMethod.print(d0.gpstime);
                // SerialMethod.print(","); SerialMethod.print(d0.date); SerialMethod.print(","); SerialMethod.print(d0.alerts);
                // SerialMethod.print(","); SerialMethod.print(d0.shocks); SerialMethod.print(","); SerialMethod.print(d0.ver);
                
                // SerialMethod.print(from); SerialMethod.print(","); SerialMethod.print(radio.lastRssi()); SerialMethod.print(",");
                // SerialMethod.print(d0.shocks); SerialMethod.print(","); SerialMethod.print(d0.lat,6); SerialMethod.print(","); 
                // SerialMethod.print(d0.lon,6); SerialMethod.println();

                break;
        case 1: //Fence packet
                break;
        case 2: //Settings Packet
                break;
        case 3: //Bias Packet
                int16_t magbias0,magbias1,magbias2;
                memcpy(&magbias0,  &buf[0],  2);   //Dest, Orig, Bytes
                memcpy(&magbias1,  &buf[2],  2);
                memcpy(&magbias2,  &buf[4],  2);

                SerialMethod.write((uint8_t *)&flagfromNode,1);
                SerialMethod.write((uint8_t *)&from,1);
                SerialMethod.write((uint8_t *)&buf,6);
                SerialMethod.println();
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

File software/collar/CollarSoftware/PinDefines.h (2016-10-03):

#ifndef PinDefines_h
#define PinDefines_h
	#include "Geofence.h"

	//I2C Addresses: MPU 0x68, POT 0x2F
	//GPS_TX, RX = Serial1
	//Serial Monitor = SerialUSB

	#define DAC_OUT     A0
	#define AMP_EN      A2
	#define AUX_0       9
	#define AUX_1       8
	#define AUX_2       A4
	#define GPS_FIX     3
	#define FLASH_CS    ATN
	#define RF_INT      2
	#define RF_CS       5
	#define MPU_INT     11
	#define CHARGE_S1   26 //PIN_LED_TXL
	#define CHARGE_S2   A5
	#define CHARGE_PG   25 //PIN_LED_RXL

	#define GPSSerial 	Serial1
	
	//Global Variables - Updatable in Web Interface
	extern uint8_t NODE_ADDRESS;
	extern uint8_t distThresh;
	extern uint8_t motionThresh;
	extern bool testing;
	extern int16_t magbias0;
	extern int16_t magbias1;
	extern int16_t magbias2;

	extern uint8_t polyCorners;
    extern struct position fencePoints[256];
    extern uint8_t fenceversion;

#endif

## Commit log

2016-05-12 Schematics almost complete
    [MainCollar.kicad_pcb, MainCollar.sch]
2016-05-12 Creating an Arduino library for the PA6C GPS
2016-05-14 Initial PCB component placement
    [MainCollar.kicad_pcb, MainCollar.sch]
2016-05-16 PCB Prototype Completed
    [MainCollar-B.Cu.gbr, MainCollar-B.Mask.gbr, MainCollar-Edge.Cuts.gbr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]
2016-05-18 Initial prototype design ready for 3D printing.
    [Assembly.SLDASM, BaseTop.SLDPRT, BaseTopRev1.STL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]
2016-05-26 Second version ready for 3D printing.
    [Assembly.SLDASM, BaseTop.SLDPRT, EnclosureBaseRev2.STL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]
2016-05-26 Renders for displaying the PCB
    [MainCollar.kicad_pcb]
2016-08-14 Updating for mistakes
    [MainCollar.csv, MainCollar.kicad_pcb]
2016-08-14 Updating for custom PCB
2016-08-15 Added Tilt corrected compass heading.
    Using the function getHeading() will return a float value of the
    compass heading adjusted based on the accelerometer orientation.
    [MPU9250.h]
2016-08-15 Added bearing2fence function
    bearing2fence() returns the Azimuth between the closest point on the
    fence and the collar device.
2016-08-28 Updating Collar firmware
    Added ability to update fence locations over LoRa.
    Using PWM output for the audio alert.
    Updated the Geofence functionality such that it returns the side
    outside, the distance outside and the bearing of the fence to the
    collar.
2016-08-28 Initial Commit of baseStation Arduino code
2016-09-05 Switched R17 and R18 to be in correct locations
    [MainCollar.kicad_pcb, MainCollar.sch]
2016-09-05 Implemented Send to Devices button
2016-09-06 Custom Board Testing - Using OSCULP32K as clock
    [arduino_zero.cfg]
2016-09-19 Basestation solid works design
    [AlexMuir-FYP.DXF, Assem.SLDASM, bottomlink.DXF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]
2016-09-19 Update board settings from LoRa packet
2016-09-20 Added storing to Flash functionality
    In the event of power loss the collar can use the values that were last
    stored in flash.
2016-09-20 Fixing issues with settings transfer
    Due to structs padding to the nearest 16 bits there were issues with
    alignment of memcpy calls
    [BaseStation.ino, serialtest.py]
2016-09-29 Bug fixes, cleaning up code.
    [BaseStation.ino, CollarSoftware.ino, PinDefines.h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]
2016-09-29 Fixed issue where an even number of fence locations didn't set the last packet flag
    [serialtest.py]
2016-10-03 Fixed sleep mode exiting immediately
    Need to ensure that the UART/I2C communications have completed before
    sleeping. Add a 100mSec delay before sleep solves this.
    [CollarSoftware.ino]
2016-10-28 Removed averaging of magnetometer
    Makes the function faster, it wasn’t really improving the smoothness of
    the output.
2016-10-28 Fixed mag calibration saving to flash issue.
    [init.ino]
2016-10-28 Solved geofence issue where direction was backwards.
    [CollarSoftware.ino]
